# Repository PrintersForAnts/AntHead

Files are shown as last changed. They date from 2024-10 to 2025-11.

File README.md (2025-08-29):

# AntHead
Toolhead for Micron and other PFA printers (Can also work on bigger 2020 based printers with the carriages linked below)

ANTHEAD GHREADME

# [Printed Part Configurator ](https://anthead.wizards-enclave.net/)

# [Color Configurator](https://hartk1213.github.io/ChromaColony/)

## BOM 
* 2x 4010 blower fans 
* 1x 2510 axial fan 
* various m3 hardware 
* BMG extruder kit , or G2 extruder kit (HGX variant is planned)
* Dragon Compatible hotend, Revo Voron, Rapido, TZV6 with or without v6 nozzle
* NOTE: if using a TZV6 hotend with the stock nozzle (small bambu style nozzle) you need to use the dragon hotend mount

What Carriage Do I Print?

Printer  | Rail 
 ----|----|
Micron/SF/Pandora | Stock [MGN9H](https://github.com/PrintersForAnts/Micron/blob/main/STLs/Gantry/Toolhead/MiniSB/MiniSB_x_carriage_MGN9H_x1.stl) | 
Micron/SF/Pandora | Stock [MGN9C](https://github.com/PrintersForAnts/Micron/blob/main/STLs/Gantry/Toolhead/MiniSB/miniSB_x_carriage_x1.stl) |
Micron/SF/Pandora | Chirpy  [MGN9H](https://github.com/chirpy2605/voron/blob/main/general/Alternative_Voron_Mounts/Modified_Mounts/Micron_Pandora/STLs/X_Carriage_MGN9H_Micron_Long.stl)
Micron/SF/Pandora | Chirpy [MGN9C](https://github.com/chirpy2605/voron/blob/main/general/Alternative_Voron_Mounts/Modified_Mounts/Micron_Pandora/STLs/X_Carriage_MGN9C_Micron_Long.stl)
V0 | Stock works but i recommend Chirpys that can be found [here](https://github.com/chirpy2605/voron/blob/main/general/Alternative_Voron_Mounts/Modified_Mounts/v0.2) 
V2/Trident | [MGN12H/MGN9H](https://github.com/PrintersForAnts/AntHead/tree/main/STLs/2020_Carriage)

## Future Plans ##
* HGX Based extruder
* Revisit BMG based extruder
* Bowden option
* larger variety of hotend mounts

## Change log ##

### 8-2-2025
* fixed offset between ducts and probe mounts that was introduced with the previous fix 

### 7-28-2025
* fixed offset between hotend mount and rear of ducts causing toolhead to tilt
* added flanged m2 heatsets in the filament path between the main body and hotend mount for use with the leafcutter 

### 6-15-2025
* Uploaded first version of assembly Manual 

### 6-10-2025
* Updated WWG2, fixed minor printablity issues
* fixed alignment on the filament sensors screw holes

### 5-27-2025
* Added Stealthfork Logo main body and LED files
* Added X endstop cable channel to the 2020 Carriage

### 4-15-2025
* Fixed fitment issue with ReVolcano mount 

### 4-11-2025
* Fixed G2 tension arm spring counterbore,
* Added Ziptie mounts for easier wire management behind ducts
* Updated Tension arm built in support

### 2-17-2025
* Updated all hotend mounts to now work with LeafCutter 
* Added new Left Ducts for LeafCutter
* Added cutting arm and blade holder
* Hotend mounts and main bodies were also merged with leafcutter, now stock and cutter bodies and hotend mounts are the same files
* Added missing tzv6 mounts and re uploaded latest hotend line up cad file

### 2-6-2025
* updated all hotend mounts to fix the mounting screw length to m3x25
* added support for Dragon Ace hotend
* added support for ReVolcano (Revo voron heatsink with hemera heatbreak and volcano heater)
* fixed rapido mount to use correct mounting m2.5 screws 

### 01-05-2025
* updated rapido mount to sit lower for HF and UHF ducts
* fixed fan intake hole size on right ducts
* added updated hotend mounts with HF and UHF nozzle location
* Added CAD and STLs for new 2020 printer carriage for MGN12h and MGN9h

### 10-30-2024
* Updated CAD to v29
* missed exporting latest right fan ducts from previous commit, they worked but had an extra chamfer that needed to be removed  

### 10-29-2024 #2
* modified main housing to now support Sherpa bolt pattern as well as Orbiter 2 bolt pattern
* ducts were updated to fit the latest change
* a Base Grill cad file was uploaded so custom grills can be made 

### 10-29-2024 #1
* Fixed an issue that was introduced with the latest LED changes from 10-28
* updated main housings, and Cad file

### 10-28-2024
* Updated assembly to v20
* Updated the LED to use the same style as Stealthburner that inserts from the bottom 
* Fixed orientation of various files 

### 10-17-2024
* Added latest CAD assembly
* removed recesses in main housing as they arent needed anymore since hotend mount screws are recessed into the printed part
* added a Voron logo variant of the main body 
* added LED logo parts for both Micron and Voron logo 
* added a dual filament sensor WWG2 variant extruder as the default extruder option in CAD 
* organized files a bit more

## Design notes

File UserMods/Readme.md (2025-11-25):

# Anthead Mods

Various mods for AntHead project
Remember to update this README when uploading new mod!

Update the following table with the information about your mod:
- Your name
- A link to your sub-folder
- A short description of your mod
- On which version of the Anthead is this mod made

| Creator | Mod title | Description | Based on Version
| --- | --- | --- | --- |
| Averen | [LED Solder Fixture](/UserMods/LED_Solder_Fixture) | Fixture for soldering up Nozzle LEDs and Body LED | Version V63 |
| Hoeby | [ZeroClick on left ducting](/UserMods/ZeroClick_left_ducting) | Using ZeroClick on the side, to keep space in the back | Version V43 |
|| [Mainbody HexZero logo](/UserMods/Main_Body_HexZero_logo) | The AntHead mainbody with the HexZero logo, incl. led | Version V43 |
| MakerMylo | [Screwless Hotend Fan Mount](/UserMods/Screwless_Hotend_Fan_Mount) | A mount for the hotend fan that uses pegs to attach to the hotend. | Version V50 |
| theFPVgeek | [Papilio Lite Extruder AntHead Mod](/UserMods/Papilio_Lite_Extruder_AntHead_Mod) | Papilio Lite Extruder modified for AntHead | Version V43 |
| Cyph3r42 | [Wristwatch-BMG dual sensor Extruder](/UserMods/Wristwatch-BMG) | A4T WW-BMG Extruder modified for AntHead | Version V72 |
| burkfers | [Bearing cutting surface](/UserMods/Bearing_cutting_surface) | Uses a small MR63 or 683 bearing as a shearing surface for leafcutter | Version V72 |
| hartk | [Crossbow](/UserMods/hartk/crossbow) | mount to use the crossbow filament cutter | latest |
|| [Trident Umbilical](/UserMods/hartk/Trident_Umbilcal) | umbilical mount for trident| latest |

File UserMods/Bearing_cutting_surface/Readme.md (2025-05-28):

# Bearing cutting surface
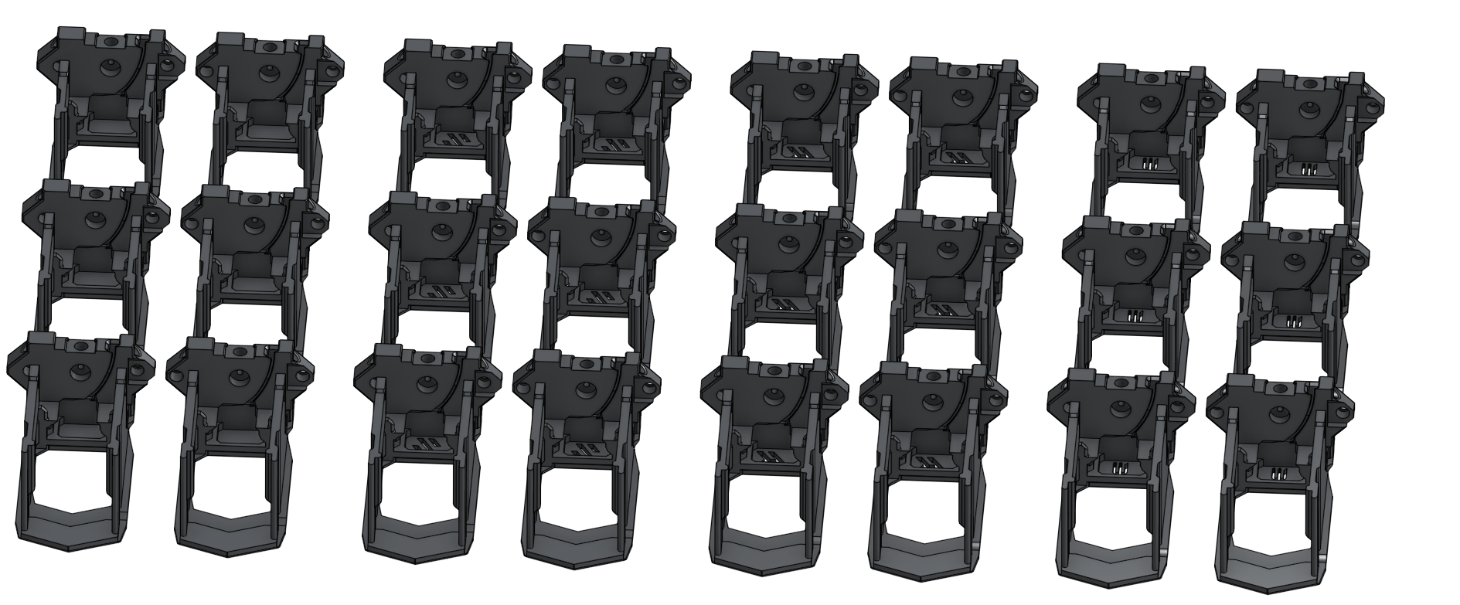
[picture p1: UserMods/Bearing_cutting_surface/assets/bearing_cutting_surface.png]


This mod replaces the main body to provide a pocket for a small bearing which will act as the shear surface for leafcutter.

To avoid tiny pieces of PTFE, the filament path is a printed 2mm diameter.

Variants for MR63ZZ bearings (6mm outer diameter, 2.5mm depth) and 683 bearings (7mm outer diameter, 3mm depth) are provided.

## Instructions
A fitment test is provided. Please print it oriented as presented to ensure it's printed in the same orientation as the full part.

Pick your desired logo, extruder mounting pattern and length for your bearing type. Print as provided, same as the original.
Ream out the filament path with a 2mm drill bit, and press the bearing into place. Glue should not be necessary.

## Caveat
The 683 bearing versions are untested, and the bearing pocket might collide with the "neck screw" heat set insert.

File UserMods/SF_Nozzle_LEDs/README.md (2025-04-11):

# Nozzle LEDs for Standard Flow Anthead

Print 1 each of the following and assemble as per the photos:
- [a]_Nozzle_LED_Carrier.stl
- [a]_Nozzle_LED_Restraint.stl

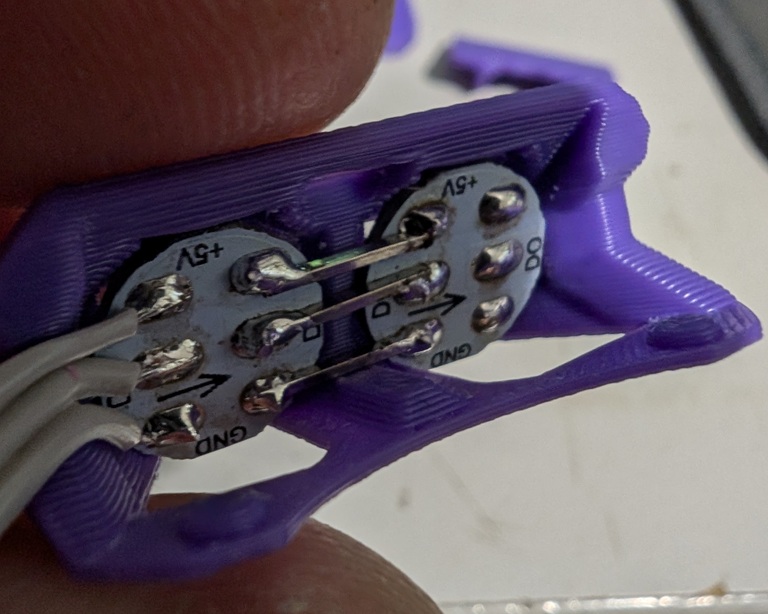
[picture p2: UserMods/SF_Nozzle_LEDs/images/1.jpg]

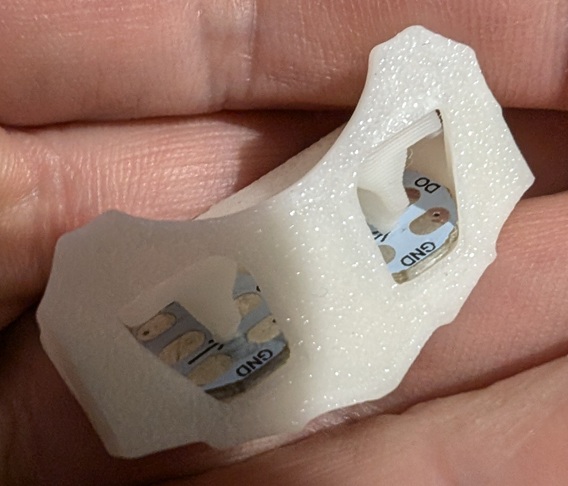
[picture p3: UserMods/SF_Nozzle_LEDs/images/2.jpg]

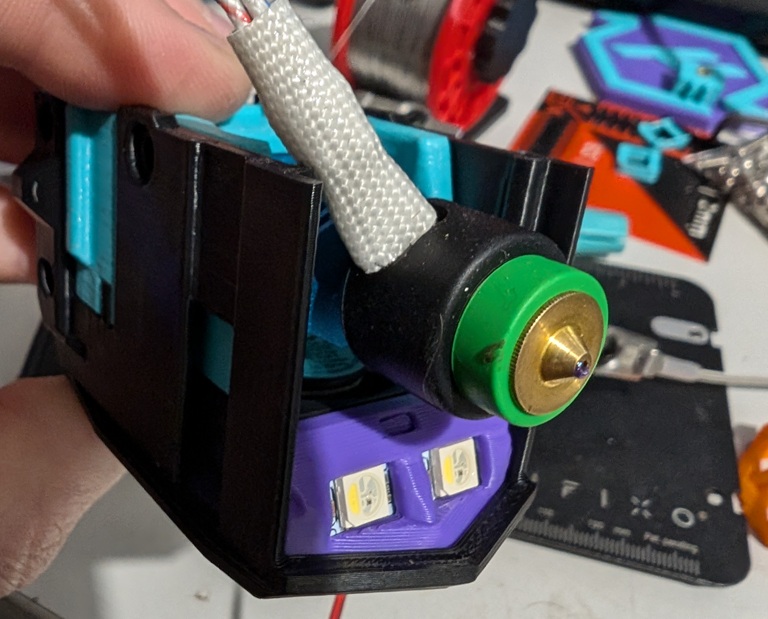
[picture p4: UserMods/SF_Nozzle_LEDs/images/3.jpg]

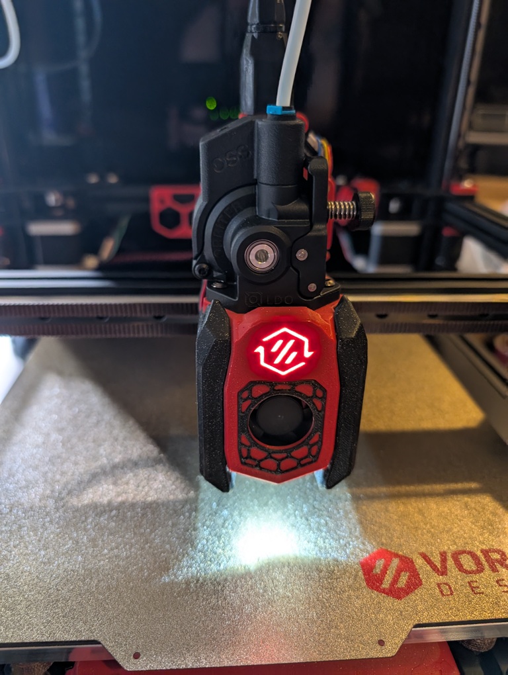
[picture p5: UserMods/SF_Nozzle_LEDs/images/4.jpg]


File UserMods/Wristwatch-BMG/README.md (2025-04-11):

[][cc-by-nc-sa]

# CURRENTLY IN BETA - USE AT YOUR OWN RISK

# AntHead WW-BMG: Wristwatch using Bondtech RIGDA with dual filament sensors for the AntHead toolhead
Originally designed by [ByThorsThunder](https://github.com/bythorsthunder) and adapted for the [A4T toolhead](https://github.com/Armchair-Heavy-Industries/A4T) by [DW-Tas](https://github.com/DW-Tas). Adapted from that adaptation for the [AntHead](https://github.com/PrintersForAnts/AntHead) toolhead (v72).

### Discord links
For discussions around AntHead checkout the PrintersForAnts section at the DoomCube discord. </br>
(https://discord.gg/armchairengineeringsux)</br>
For discussions around the A4T toolhead checkout Armchair Heavy at their discord. </br>
Join me on Discord (https://discord.gg/armchairengineeringsux)
</br>

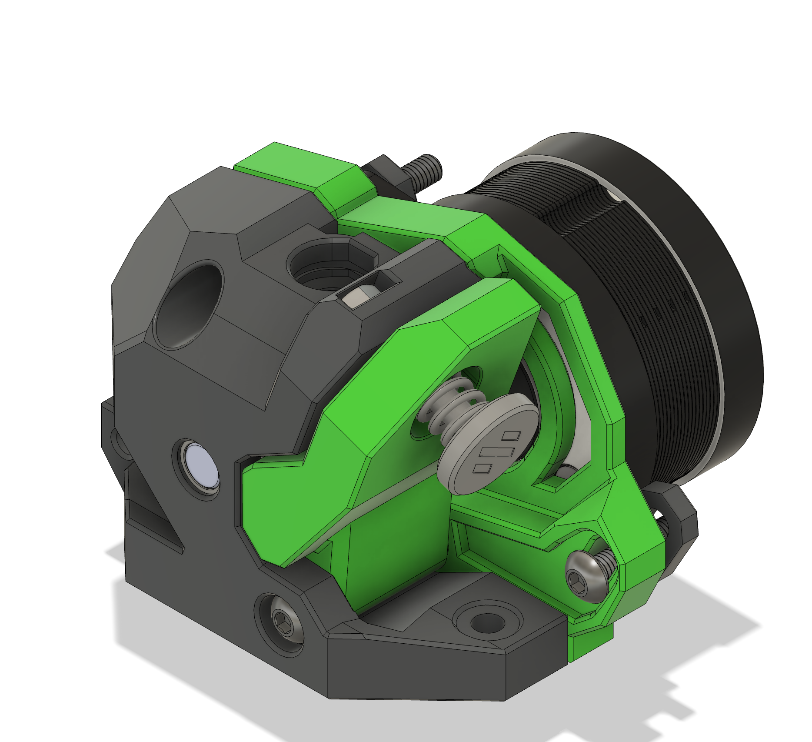
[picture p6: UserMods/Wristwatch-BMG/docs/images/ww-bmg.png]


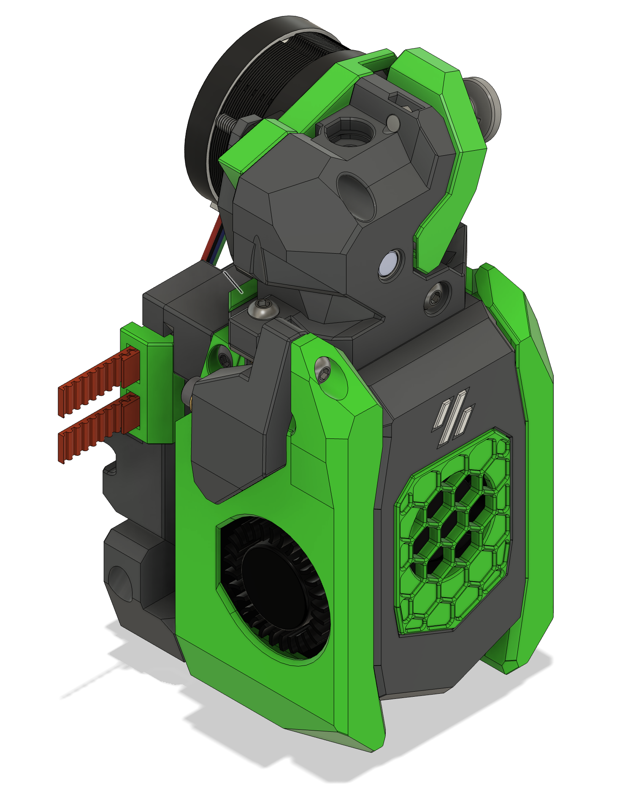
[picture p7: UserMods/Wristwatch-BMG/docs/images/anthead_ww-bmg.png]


<br/> 
I had BMG gears lying around and wanted to use that for an AntHead build to use with BoxTurtle. The A4T adaptation already had the dual sensors and just needed some tweaking to make it work with AntHead and LeafCutter. <br/><br/>

## Bill of Materials (BOM)
***`*Not including carriage hardware`***
| Qty | Item | Notes |
| --- | --- | --- |
| 2 | M3 Nut | Using normal nuts because you probably have them. Tolerances should be tight enough to prevent spin. |
| 1 | M3 x 20 BHCS | Top Motor screw.  At least M3x18 BHCS |
| 3 | M3 x 14 BHCS | Bottom Motor mount.  You'll need M3x14 for mounting to the AntHead and for the LeafCutter lever arm | 
| 1 | M3 x 12 BHCS | Second mounting screw for the AntHead |
| 1 | M3 x 30 BHCS				| Mount Tension arm to body |
| 1 | ECAS | |
| 1 | RIDGA / BMG hardware set | If standard BMG configure for RIDGA |
| 2 | 20mm long 3mm internally threaded stand off  | To attach toolhead board to the back of the extruder motor |

## Printing parts
### Print settings
Parts are meant to be printed in 0.2mm layer heights, 0.25mm first layer should be OK. Anything else will likely cause the built-in supports to fail or fuse to the printed part.<br/>
Print testing is still TBD<br/>

Voron settings are a good starting point for 0.4mm wall widths (four walls, 5 top/bottom layers and 40% infill).<br/>

### Credits
* Huge thanks to DW-Tas for the bulk of the modifications to the Wristwatch for dual sensors
* Also big thanks to ByThorsThunder for the original design

This work is licensed under a
[Creative Commons Attribution-NonCommercial-ShareAlike 4.0 International License][cc-by-nc-sa].

[][cc-by-nc-sa]

[cc-by-nc-sa]: http://creativecommons.org/licenses/by-nc-sa/4.0/
[cc-by-nc-sa-image]: https://licensebuttons.net/l/by-nc-sa/4.0/88x31.png
[cc-by-nc-sa-shield]: https://img.shields.io/badge/License-CC%20BY--NC--SA%204.0-lightgrey.svg

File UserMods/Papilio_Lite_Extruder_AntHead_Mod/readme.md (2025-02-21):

# AntHead Papilio Lite Mod

In Progress:  Leafcutter (Filament Cutter) + Integrated Runout Sensor









## About
AntHead modified to integrate Papilio Lite<br>
Wanted to lower the height of a standard AntHead with standard Papilio Lite extruder.<br>
Thanks [hartk](https://github.com/hartk1213) the creator of the AntHead [Anthead](https://github.com/PrintersForAnts/AntHead) and [Kevinakasam](https://github.com/kevinakasam) the creator of the Papilio Lite [Papilio Lite](https://github.com/theFPVgeek/Papilio-Belt-Extruder/) for having solid base to use to make this work. <be>




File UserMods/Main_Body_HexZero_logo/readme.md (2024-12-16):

# MainBody with HexZero logo included led option
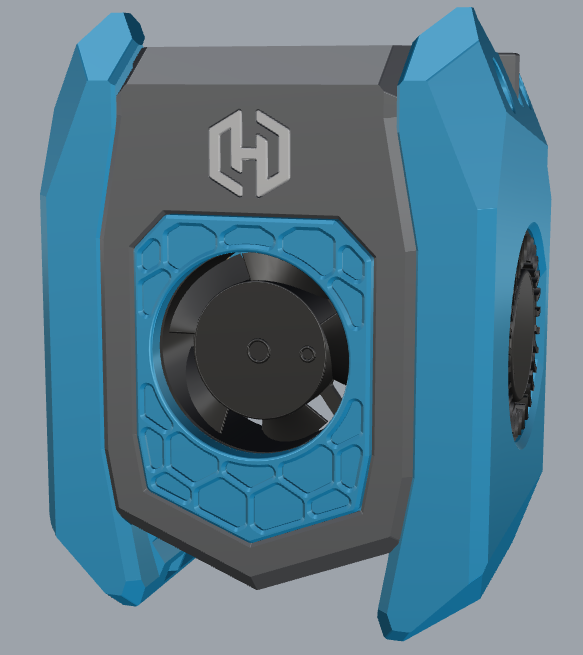
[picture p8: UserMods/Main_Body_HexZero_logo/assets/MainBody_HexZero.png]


This mod is made for the HexZero. <br>
[Github link HexZero](https://github.com/Alexander-T-Moss/Hex-Zero) 

## Which 3d parts are shared
Only the modded parts can be find in this mod. <br>
This includes the parts for the led. <br>
Non modded parts, that are the default AntHead parts and can be find in de main repository of the AntHead. <br>
The parts are made on AntHead version43

## Be carefull
Be carefull when you assemble the led.
Because of the design of the HexZero logo and the space that is availble, the parts are thin.
Take this in care, when you assemble the mainbody.

## Hardware needed for this mode
### For the AntHead
Nothing extra is needed for the AntHead, when looking at the hardware. <br>

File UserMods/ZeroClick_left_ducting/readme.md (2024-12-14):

# ZeroClick on left ducting
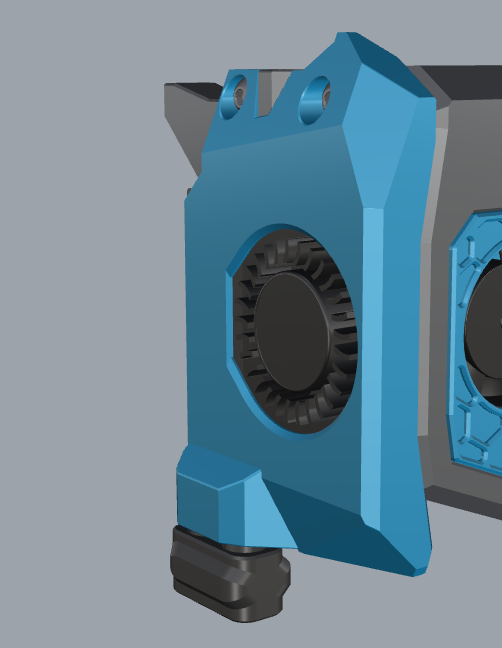
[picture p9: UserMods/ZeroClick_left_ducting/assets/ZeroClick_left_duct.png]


## Idea about this mod
This mod is started for the HexZero. <br>
The HexZero has the dual extrusions in the back, like the Voron V0.2. <br>
On the HexZero the change is made, that the gantry can move over these dual extrusions. <br>
There is that little space, that there can't be parts on the back of the toolhead, because these would collide with these Z-extrusions. <br>
This mod moves the probe to the side, to give free space on the back, to prevent this collision. <br>
[Github link HexZero](https://github.com/Alexander-T-Moss/Hex-Zero) 

## Which 3d parts are shared
Only the modded parts can be find in this mod. <br>
Non modded parts, that are the default AntHead parts and can be find in de main repository of the AntHead. <br>
Only the standard fan is modded. Other fan ductings are not changed, but could be done by de delivered CAD.

## Hardware needed for this mode
### For the AntHead
Nothing extra is needed for the AntHead, when looking at the hardware. <br>
### For the ZeroClick
The default parts for the ZeroClick are needed. <br>
Extra parts could be the parts for the dock, depends on the user choice, what to use. <br>
For the ZeroClick follow there github. <br>
[Github link ZeroClick](https://github.com/zruncho3d/ZeroClick) 

## How to wire the ducting
Before following the ZeroClick manual, the explanation how the wiring has to be done
### Step 1
Start by placing wire in the wire-guide of the front magnet-hole and let it stick out of the back. <br> 
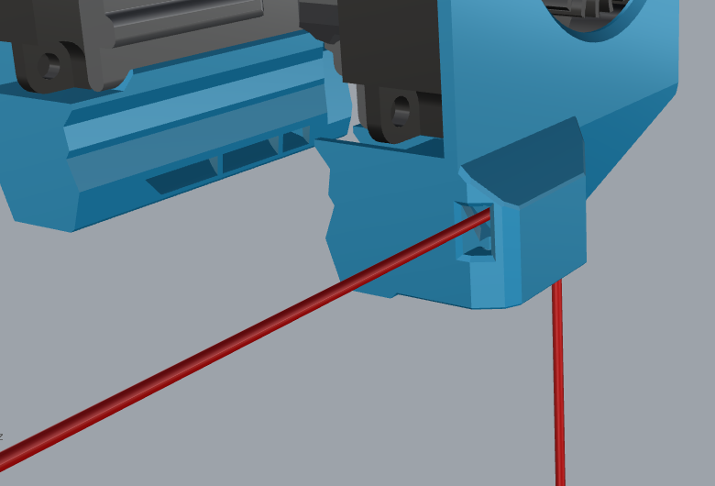
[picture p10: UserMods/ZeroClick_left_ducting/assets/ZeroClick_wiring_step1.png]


### Step 2
Loop back the wire and place it back in the hole it comes out, but now in the wire-guide that goes underneat the fan. <br> 
Carefully pull on the wire end and help them, that the loop disappears inside the ducting, and nothing is sticking out the back. <br>
Not easy to draw in Rhino, to make a wire loop, but you will get it what i mean :blush: <br>
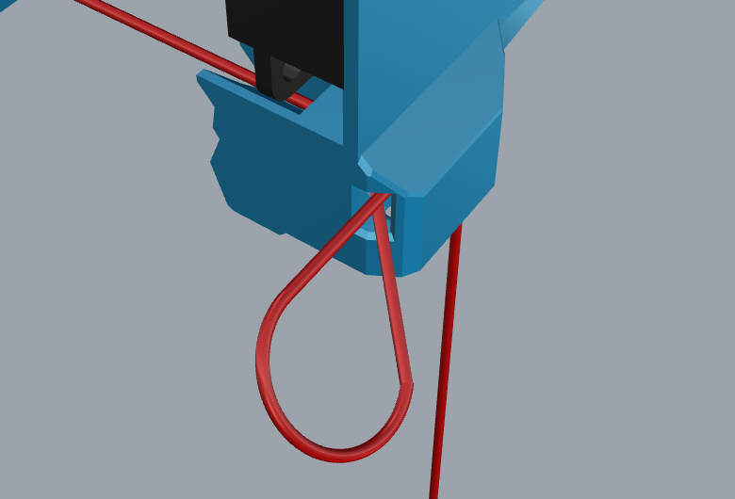
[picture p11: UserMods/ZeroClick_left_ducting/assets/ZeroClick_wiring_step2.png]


### Step 3
Place the wire-guide of the back magnet-hole. <br> 
This wire-guide hole is almost in line with the wire-guide underneat the fan, that you can route it in a single job. <br>
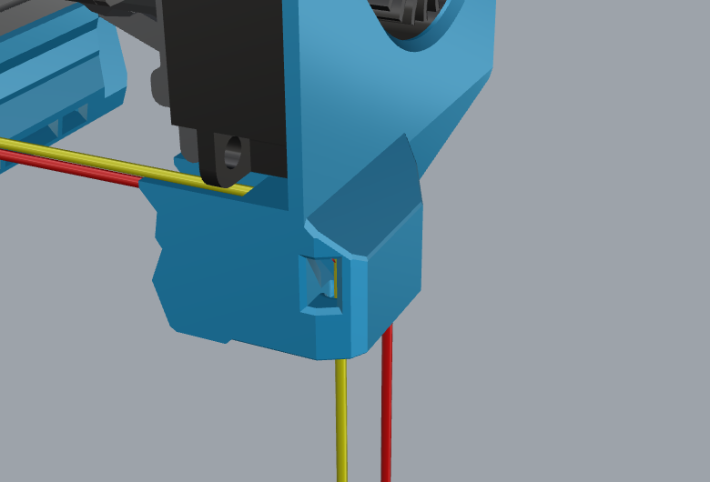
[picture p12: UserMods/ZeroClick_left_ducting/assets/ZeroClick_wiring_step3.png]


### Step 4
Now that the ZeroClick wires are near the fan, follow the wire route of the fan.
How to finish the wiring for the ZeroClick magnets, see the ZeroClick manual on there github

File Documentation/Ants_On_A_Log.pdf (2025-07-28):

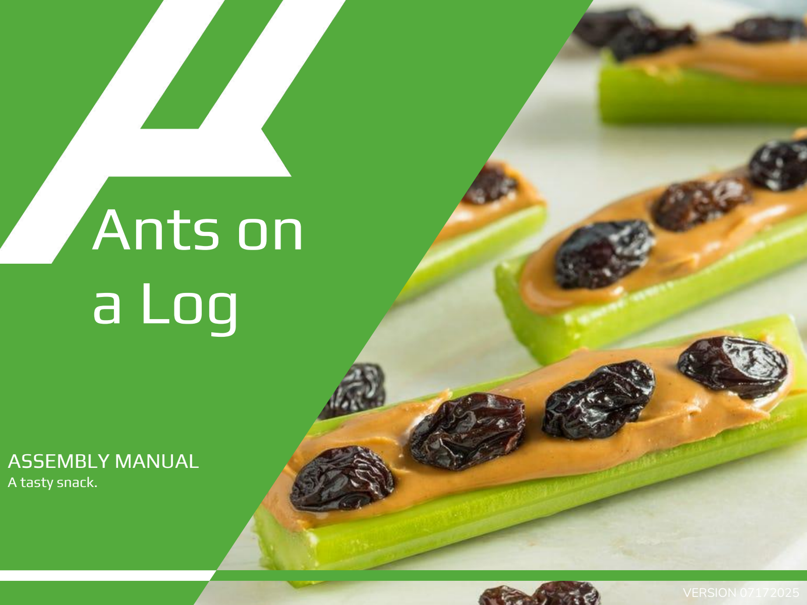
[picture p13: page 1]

# ASSEMBLY MANUAL

A tasty snack.

# Ants on a Log

### VERSION 07172025

TABLE OF CONTENTS

TABLE OF CONTENTS

Ants on a Log

Description | Page | Description | Page
1 | Introduction | 3
2 | Prep Work | 4
3 | Assembly | 5

2

INTRODUCTION

Ants on a Log | 3

### Ants on a Log

### Ants on a log is a wonderful snack that is super easy to make. Ready in no time you can have a tasty snack that will nourish your mind and body to help you finish building your toolhead, printer, or what ever other project you are tackling! You only need the three

following ingredients to make this wonderful snack.

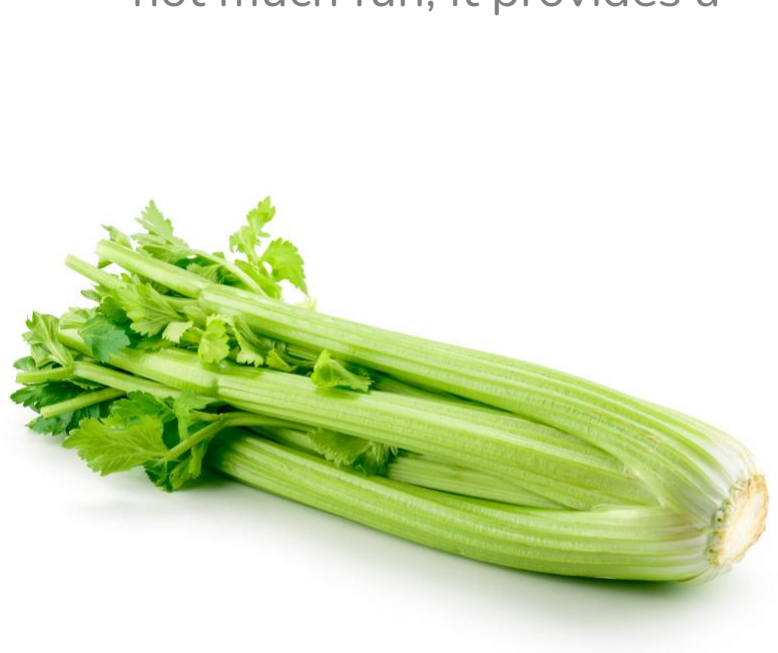
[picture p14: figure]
base for this yummy snack.

Celery
While on its own celery is not much fun, it provides a

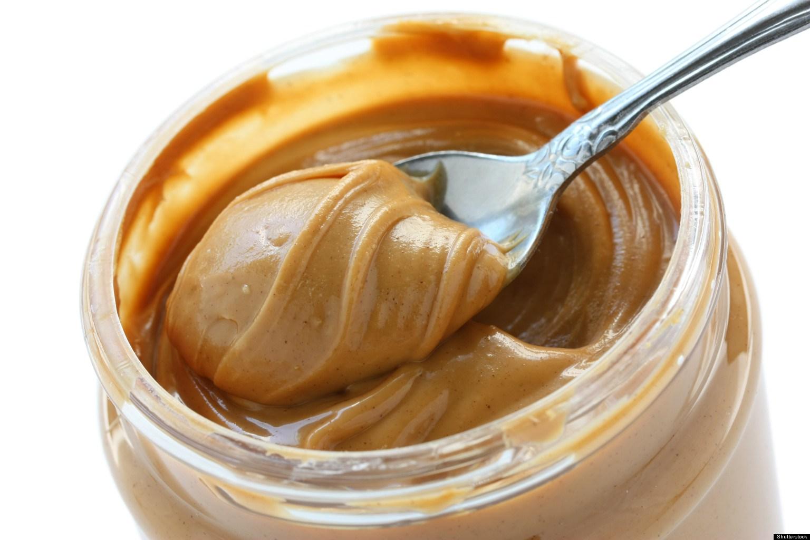
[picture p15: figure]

Peanut Butter
This will be the core and
glue that holds this snack together.

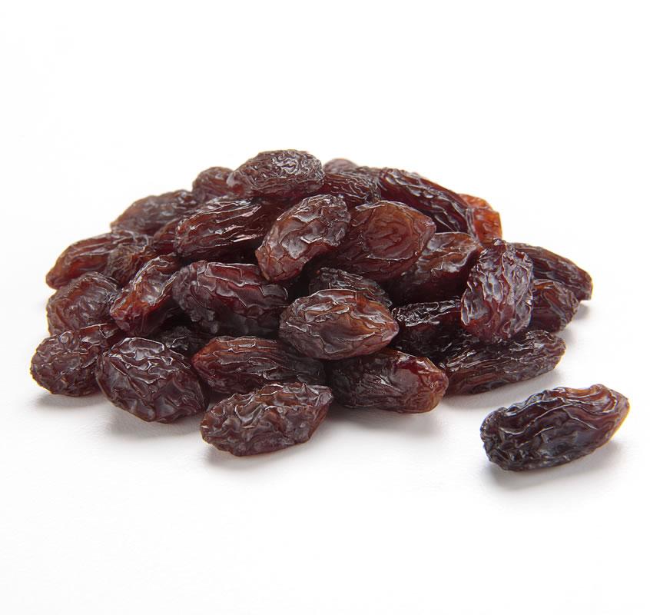
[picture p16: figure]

Rasins
The tasty toppers to our
wonderful snack.

INTRODUCTION

### Prep Work

You will need to do a little prep work before beginning to make your snack.

### Next you will need to wash your celery. (unless you bought it pre cleaned and cut)

The last bit of prep work will be chopping your celery into sections that are about 3 inches

### long. Be careful to only cut the celery and not yourself!

Area Prep
The first thing you will
want to do is ensure you
have a clean work area.
Wipe the area down with
a food area safe cleaning
solution.

Clean Your Celery
Next you will need to
wash your celery.
(unless you bought it pre
cleaned and cut)

Chop Your Celery
The last bit of prep work
will be chopping your
celery into sections that
are about 3 inches long.

Be careful to only cut the celery and not yourself!

You will also want to have a plate or some other means of containment for your snacks once they are prepared.

### Assembly

INTRODUCTION

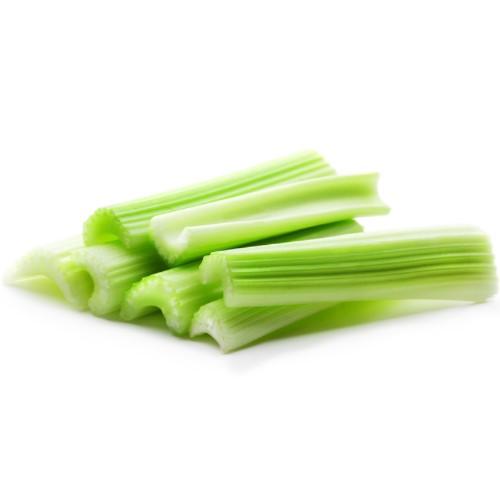
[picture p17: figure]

Get Your Celery
Place your celery stick with the channel facing up in your hand.

Make sure you have a solid grip on it.

### Assembly

INTRODUCTION

Add Peanut Butter
Using a spoon spread a good amount of peanut butter in the channel of your celery. Make sure you get a good thick coating and don’t skimp here!

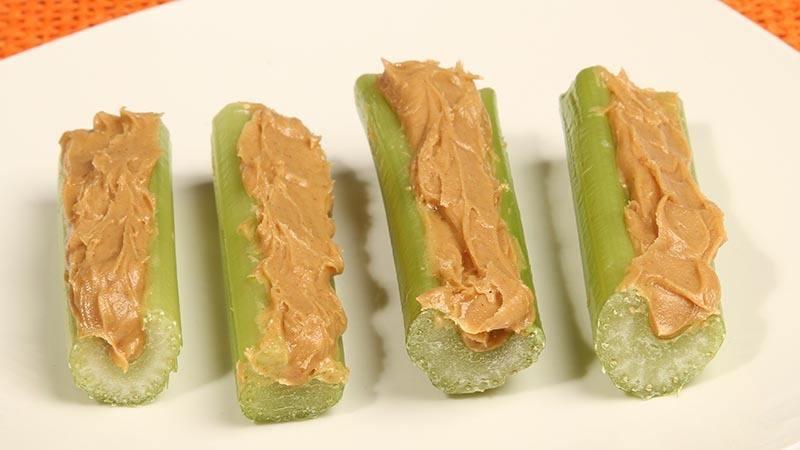
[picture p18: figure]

### Assembly

INTRODUCTION

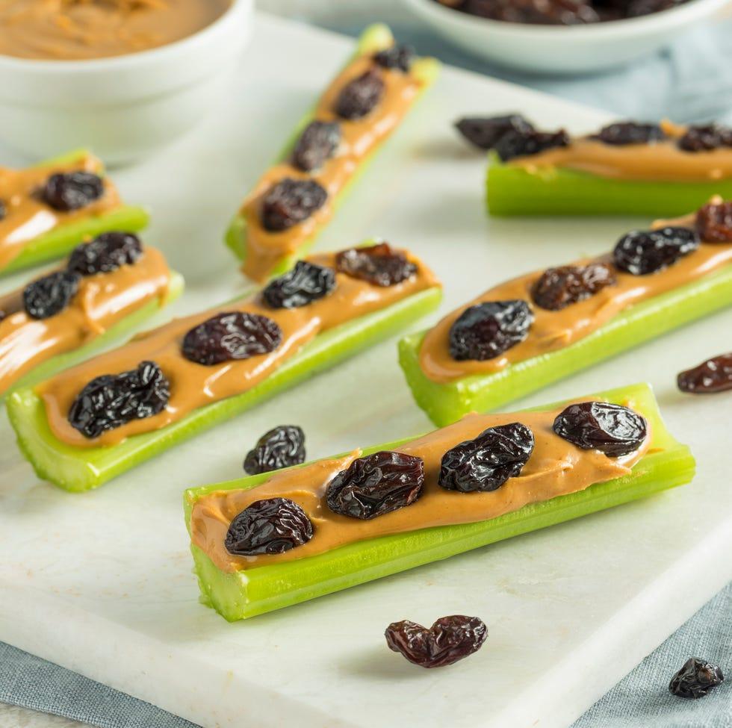
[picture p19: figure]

Place Your Ants
Now comes the fun part! You get to put your ants on the log!

Take your raisins and line them up down the peanut butter in a little row.

### Ants of the World

INTRODUCTION

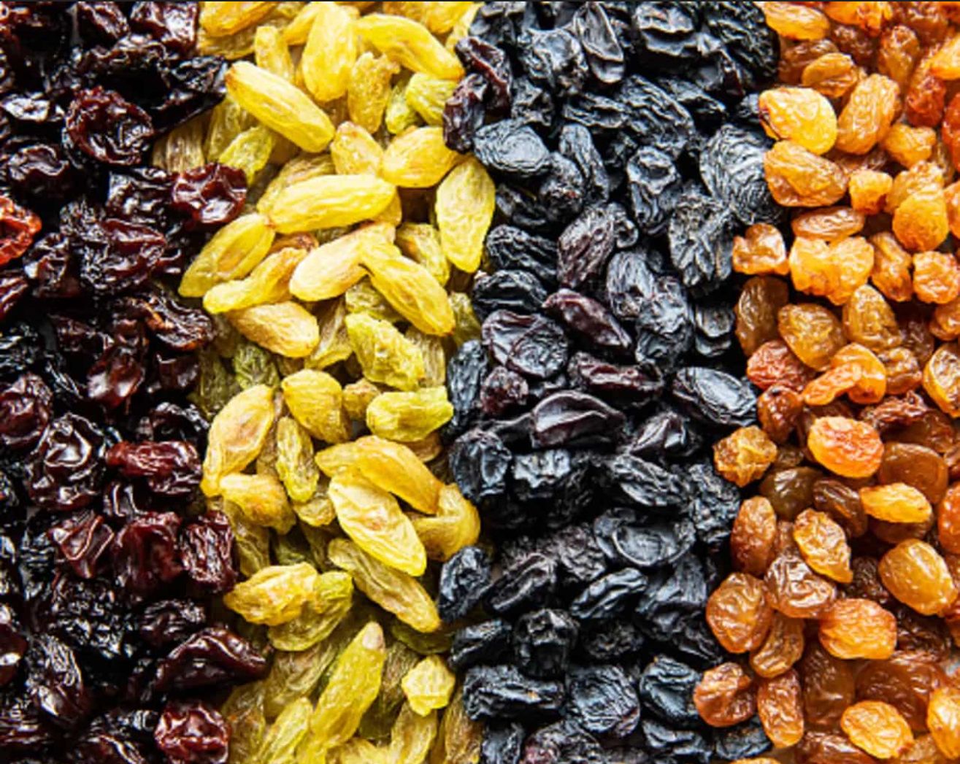
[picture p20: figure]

Many Kinds of Ants in the World
There are many kinds of ants in the world in many different colors and sizes. Have fun, mix things up, and try them all!

### Enjoy!

INTRODUCTION

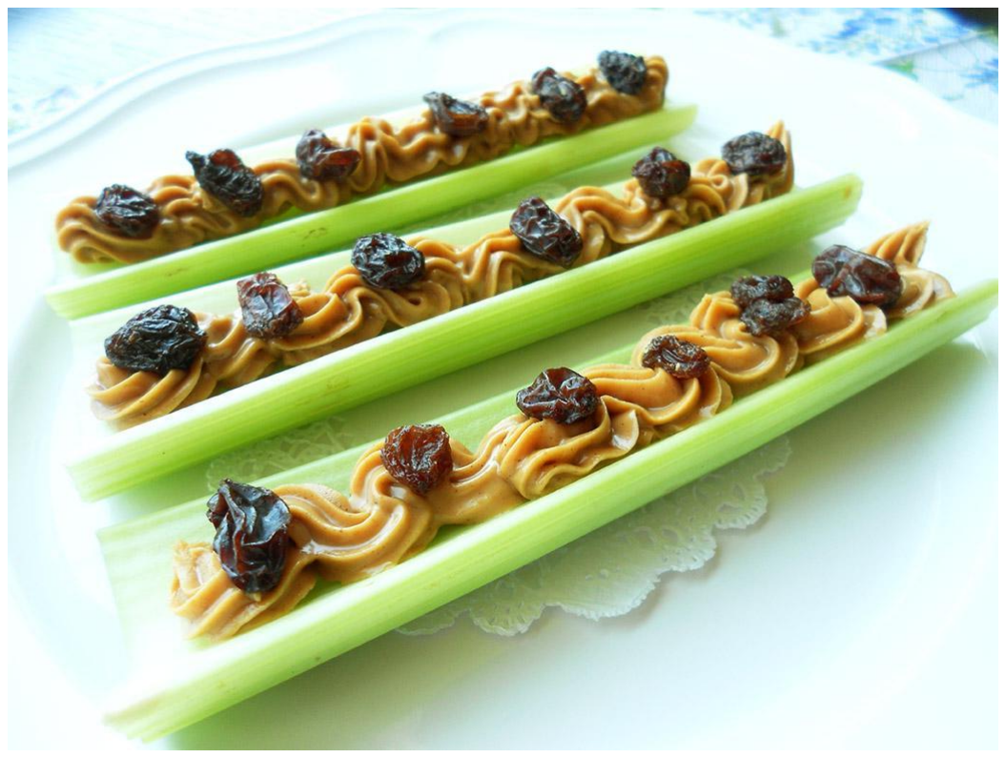
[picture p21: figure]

Enjoy!
Now that you have made your super posh and delicious snack enjoy it! Because soon it will be time to get back to working on printers!

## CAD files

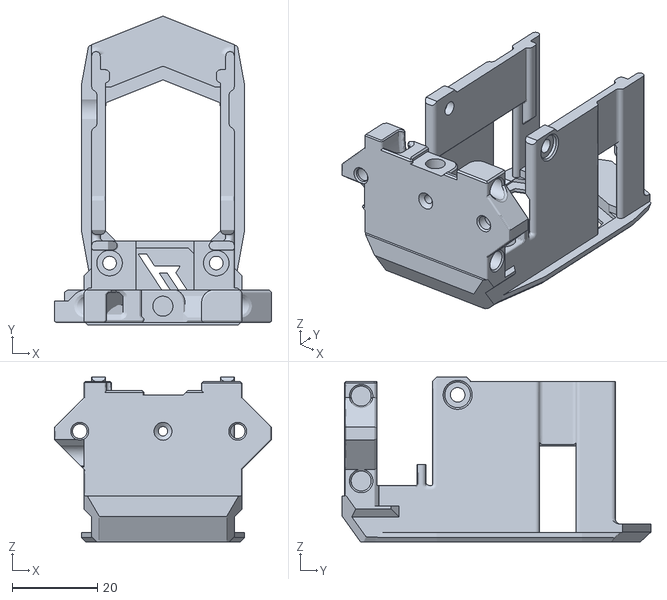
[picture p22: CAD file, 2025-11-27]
STLs/Main_Bodies/O2/Micron/ant_head_main_body_micron_o2_hf_x1.stl
50.8 x 72.3 x 38.6

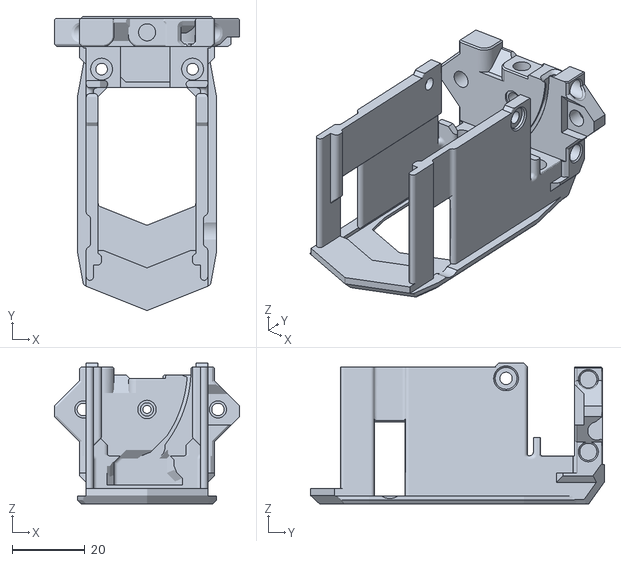
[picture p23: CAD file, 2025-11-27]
STLs/Main_Bodies/O2/No_Logo/ant_head_main_body_no_logo_o2_uhf_x1.stl
50.8 x 80.8 x 38.6

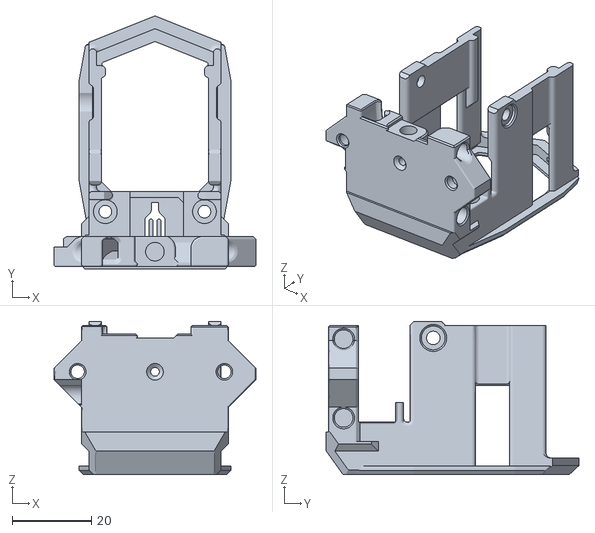
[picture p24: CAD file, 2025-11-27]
STLs/Main_Bodies/O2/SaladFork/ant_head_main_body_saladfork_o2_sf_x1.stl
50.8 x 63.8 x 38.6

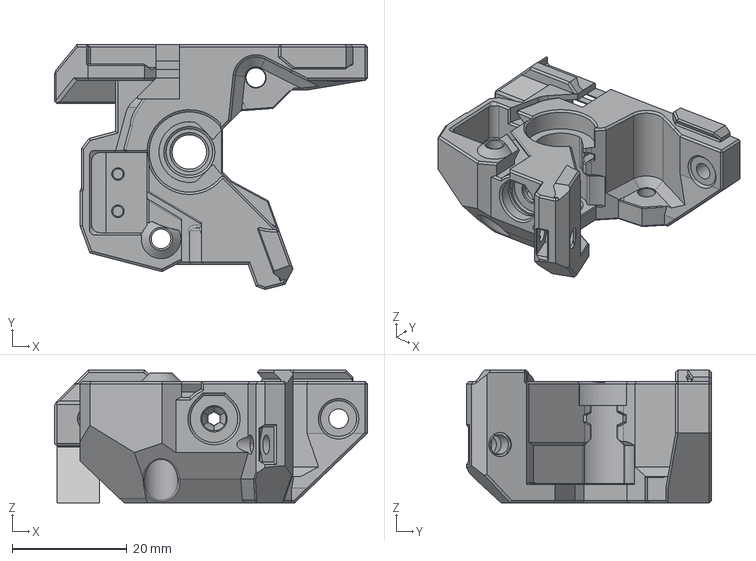
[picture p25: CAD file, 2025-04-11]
UserMods/Wristwatch-BMG/CAD/AntHead WW-BMG - Main Body.step
54.6 x 42.8 x 23.2 mm

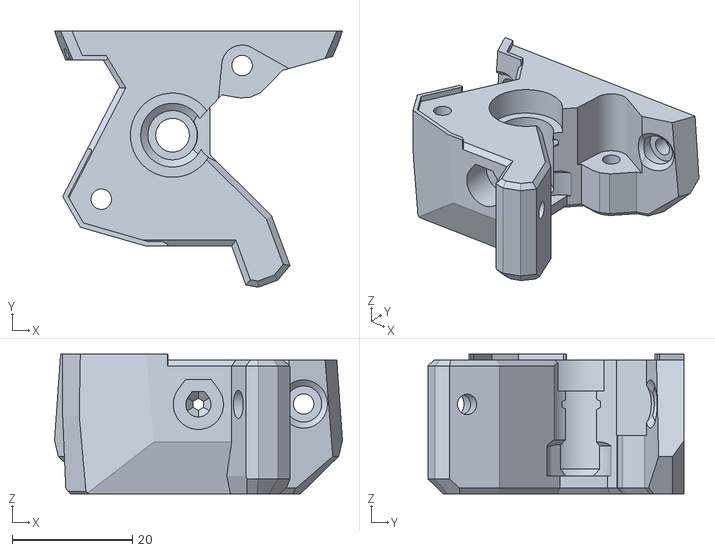
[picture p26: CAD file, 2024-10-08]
STLs/Extruders/BMG/extruder_main_body_x1.stl
47.9 x 42.7 x 23.3

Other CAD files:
STLs/Main_Bodies/O2/StealthFork/ant_head_main_body_stealth_fork_o2_uhf_x1.stl
STLs/Main_Bodies/O2/Voron/ant_head_main_body_voron_o2_hf_x1.stl
STLs/Main_Bodies/Sherpa/Micron/ant_head_main_body_micron_sherpa_hf_x1.stl
STLs/Main_Bodies/Sherpa/No_Logo/ant_head_main_body_no_logo_sherpa_uhf_x1.stl
STLs/Main_Bodies/Sherpa/SaladFork/ant_head_main_body_saladfork_sherpa_hf_x1.stl
STLs/Main_Bodies/Sherpa/StealthFork/ant_head_main_body_stealth_fork_sherpa_hf_x1.stl
STLs/Main_Bodies/Sherpa/Voron/ant_head_main_body_voron_sherpa_hf_x1.stl
UserMods/Bearing_cutting_surface/CAD/683/Main_Body_Voron_Sherpa v4_683.step
UserMods/Bearing_cutting_surface/CAD/MR63ZZ/Main_Body_Voron_O2_UHF v4_MR63ZZ.step
STLs/Main_Bodies/O2/Micron/ant_head_main_body_micron_o2_sf_x1.stl
STLs/Main_Bodies/O2/No_Logo/ant_head_main_body_no_logo_o2_sf_x1.stl
STLs/Main_Bodies/O2/SaladFork/ant_head_main_body_saladfork_o2_hf_x1.stl
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

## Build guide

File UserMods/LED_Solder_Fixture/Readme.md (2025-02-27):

# AntHead LED Solder Fixture
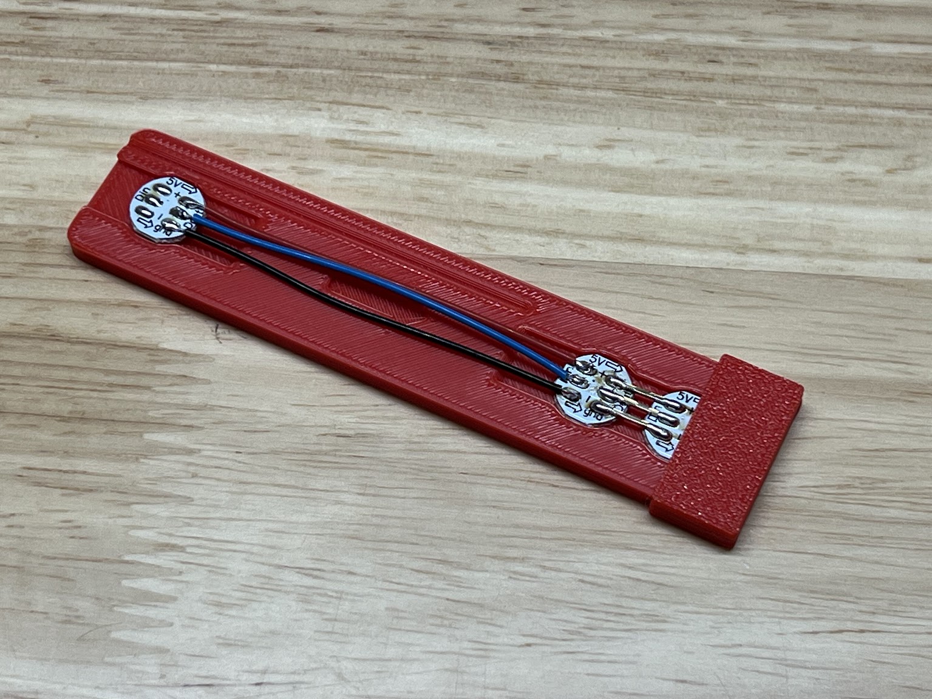
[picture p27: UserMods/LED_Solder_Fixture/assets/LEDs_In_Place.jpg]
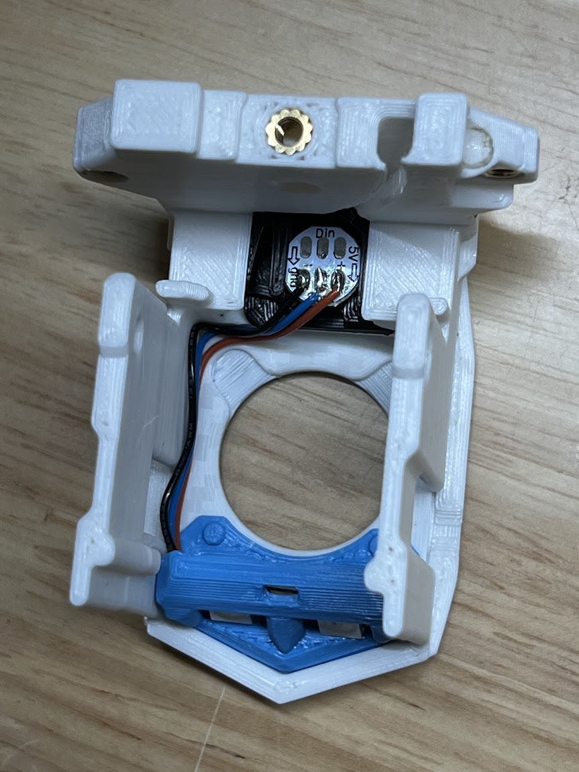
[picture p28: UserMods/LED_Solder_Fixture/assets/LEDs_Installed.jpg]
<p align="center"><br>

## What is this?

This is used to hold the LEDs for soldering when using the Nozzle LEDs and the Body LED in the AntHead.  It also provides a wire length measurement in the groove.  

## How to use

- Use the groove to cut the wires to length
- Insert the LEDs 
- Solder the 2 nozzle LEDs first.  I recommend using some rigid pins or solid wire. Small tweezers help.

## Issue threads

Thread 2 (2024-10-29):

grill no longer fits after new LED insert update

hartk1213, 2024-10-29:
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

Closed 2024-10-29.

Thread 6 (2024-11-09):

HB92 Grill does not fit fan correctly.

dajones89, 2024-11-09:
Left hand duct does not fit the HB92 fan correctly. Due to the position of the hole, the fan blades are partially covered, jammed by the duct.
[left_duct_HB92_x1.stl](https://github.com/PrintersForAnts/AntHead/blob/main/STLs/Ducts/%5Ba%5D_left_duct_HB92_x1.stl)
I had initially fixed this by moving the hole 1.5mm to the rear, sadly no longer have the CAD file but have the 3MF that I could share.

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

dajones89, 2024-11-09:
Just to add, the right hand side does fit correctly

Closed 2024-12-14.

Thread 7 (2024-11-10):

Duct face is unnecessarily thin

PedroC1999, 2024-11-10:
Although what could be partially blamed on my cheap fan or printer calibration, I have found the fan ducts to be a bit weak during assembly and crack if the fan fit isn't perfect. I have also found that my Kingroon fan blades (HB form factor using HB ducts) protrude further than the duct face

"Pulling" the face 0.5mm is enough to fit 4 complete walls, instead of 2 walls + gapfill and means the fan blade now sits closer to flush and is protected during potential sensorless homing. 0.5mm pull means the geometry is unchanged (atleast using the HB ducts) and the styling is therefore unaffected. This added thickness allowed me to assemble the ducts without cracking and with alot more confidence.

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

pm0u, 2025-06-12:
Maybe its your wall generator? I was able to get 4x walls in this area with arachne and 55% min wall width (might not be necessary to go that low). Inner walls ended up around 0.24mm.

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

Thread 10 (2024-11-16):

3010 hotend fan for us Europeans ? :)

ga73, 2024-11-16:
Awesome design but 2510 (at least delta fans) are hard to source in Europe or shipping is way more than the cost of the fan!!

Any thoughts of a design which will accept 3010 hotend fans for us Europeans ? 👍

EllaFoxo, 2024-12-10:
@ga73 I got mine from 3Dkatten in Sweden. Might suggest taking a look there? 😄

https://3dkatten.se/en/products/delta-2510-5v

azak1r, 2025-02-21:
i got them from digikey in europe. in order to save on shipping i ordered multiple things like 2510's aswell as other goodies for the toolhead (running 6)

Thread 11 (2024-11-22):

30mm hotend screws bottom out on all carriages

Foofinator94, 2024-11-22:
The update to 30mm length from 25mm doesn't work right now. The screws bottom out on both printed and CNC carriages before fully clamping the hotend mount.

Reccomend to make the clamped thickness increase by ~0.8mm to accomodate, or revert to the previous design with 25mm screws as that was working fine.

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

hartk1213, 2024-12-16:
where did you see that it uses 30mm? those should still be 25mm

Foofinator94, 2024-12-16:
The previous iterations had more recessed counterbores for the screws, so needed 25mm. The latest didnt have enough thread engaging for 25mm so I thought 30mm was needed.

Closed 2025-02-06.

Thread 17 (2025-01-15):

the bambu x1 hotend needs to shft to the side a little

broncosis, 2025-01-15:
when you put the hotend on its mount into the tool it forces the side of the cowl
out a little bit I will take some pictures and post in a little bit

granted I pulled it out of you hotend line up step file so I don't think its Released yet but I wanted to test I may try and pull it into fusion
and make the slight adjustments just over a millimeter

broncosis, 2025-01-15:
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

broncosis, 2025-01-15:
I made some minor tweaks to hotend mount printing it tonight I will update

@hartk1213  thank you for the work you have put in sofar if this work I will have to figure out git and put in a pull request

broncosis, 2025-01-16:
Yes a 1.1mm adjustment
Was perfect
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

tjeffoo, 2025-04-02:
Where can i get this hotend mount file? Its different from the one in the stl map. With the one in the stl map the x1c hotend does not fit with the stealthchanger backplate. This one is 90 degrees turned.

broncosis, 2025-04-04:
@tjeffoo  are you on the stealth changer Discord message me there I will send you my file to try out

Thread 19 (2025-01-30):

LED Carrier for Rainbow Barf

angaz, 2025-01-30:
It would be pretty cool to have an LED carrier for the [Rainbow Barf](https://github.com/VoronDesign/VoronUsers/tree/main/printer_mods/VinnyCordeiro/RGB_LED_grid_for_SB).

The logo cutout is slightly too small, like 1-2mm, but I think with the diffuser, it will be fine. It just fits into the hole where the LED goes without the carrier, so I guess it should be possible to design.

I exported the PCB as a step file: [RGBW_LED_circular_panel_for_Stealthburner.step](https://github.com/angaz/VoronUsers/blob/daeb15535c91fa9469d36fe5c07573f2e3aefe4d/printer_mods/VinnyCordeiro/RGB_LED_grid_for_SB/KiCad/RGBW_LED_circular_panel_for_St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)

Here are some pictures for reference:

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

angaz, 2025-01-30:
Brainfart moment, I need to print this: https://github.com/tanaes/whopping_Voron_mods/tree/main/LEDs/Rainbow_Barf_Logo_LED

Closed 2025-01-30.

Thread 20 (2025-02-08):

Rapido Hotend Mounts have missing buffer

dazza2924, 2025-02-08:
Looks like that the '[a]_rapido_x1.stl' and '[a]_rapido_m2.5_x1.stl' have a screw hole that is larger than the rest of them, which means that when screwing in the screw for the Rapido Hotend, it will bottom out. Expecting to see all 4 holes be the same (the current 3 holes appear to be correct).

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

Theaninova, 2025-02-22:
Seems like that was fixed in d0741df254f2a084a1baa9b44a569ffbefc1e9f4

Closed 2025-02-27.

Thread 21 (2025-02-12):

Missing leafcutter stl files

ga73, 2025-02-12:
Hi,  seems like some of the stl files are missing for the leaf cutter going from the cad.

Also will you be releasing a rapido mount for the leafcutter as well as revo and dragon versions?

Thanks!

hartk1213, 2025-02-27:
all files have been updated in the main repo , not in the usermods folder

Closed 2025-02-27.

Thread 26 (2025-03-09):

Cartographer CNC adapter 9mm belts doesnt fit right

ga73, 2025-03-09:
Hi,
Tried using the Carto CNC adapter (HF) with a rapido - the adapter, no matter how much it's adjusted is the wrong height to trigger the cartographer.

This is using a cartographer 9mm belt size HF CNC bought directly from them.

Does the adapter only fit 6mm belts ?  if so it maybe good to point this out (and any chance of a 9mm belt version if thats the case ??! :) )

ga73, 2025-04-26:
any chance this could be looked at...would really like to try this toolhead :)

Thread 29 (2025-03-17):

G2 Rear Plate Wire Cut Outs (Stealthchanger)

EddieSha04, 2025-03-17:
When using Anthead/G2 on stealthchangers, the rear plate will pinch the wires on the spacer/backplate.
-Enlarge wire cutout on the right to account for RGB, post sensor wires and thermistor/heater wire.
-Provide cut out on the left for wiring as well.

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

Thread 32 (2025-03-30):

Extruder mounting holes

rbc1225, 2025-03-30:
I printed out both extruders under STLs and then Extruders and neither one of them line up with the mounting holes on the shell. I may be doing something wrong but I then printed out a Sherpa Mini extruder from another source it is spot on to be able be mounted to the shell. As you can see, I printed both bases from the extruder directory and both are spaced the same and don't line up with the shell.  I even tried your adapter plates thinking something would line up there. No luck. Anyway, not exactly sure how this works on Github but that's what I found.

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

bcutty, 2025-03-30:
The two anthead extruders have been altered from the orbiter mounting pattern wwbmg and wwg2, so you’d need to print the orbiter mounting pattern cowl for the holes to line up instead of the sherpa mini one.

rbc1225, 2025-03-31:
> The two anthead extruders have been altered from the orbiter mounting pattern wwbmg and wwg2, so you’d need to print the orbiter mounting pattern cowl for the holes to line up instead of the sherpa mini one.

Ahhh Okay, I will look into that.  Thanks

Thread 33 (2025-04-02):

VORON Mainbody - UHF and HF same size

weismantelf, 2025-04-02:
Hello,

is it correct that the VORON mainbody's UHF and HF have the same size.
I was cross checking with the assembly file and there you have 3 sizes for the main body.

weismantelf, 2025-04-04:
Sorry I was wrong

Closed 2025-04-04.

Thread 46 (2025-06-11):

Add HEF wire routing slots in hotend mounts - @theroguezeta

hartk1213, 2025-06-11:
Along with this, we can also look at removing the slots on the main body that were used to route the fan wires out.

We may want to add additional space in the slot where the wires exit as we are now adding 3 more wires. The Delta fan wires are about 0.95mm in diameter.

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

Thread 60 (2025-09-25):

WWBMG does not have cutouts for wire exits

hartk1213, 2025-09-25:
From Steve Build's stream, there are no wire cutouts on the BMG extruder and does not work with the Vitalii CNC bracket.

<details>
<summary>Context from Discord</summary>

**Submitted by:** `theroguezeta`
[View original Discord message](https://discord.com/channels/825469421346226226/1316975035478577172/1420565895482179636)

</details>

---
**Attached Images:**

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

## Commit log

2024-10-08 initial commit with CAD and STLs more to come soon
    [[a]_dragon_hotend_mount.stl, [a]_fan_grill_hex.stl, [a]_fan_grill_open.stl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]
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2024-10-09 updated STLs and CAD to v7
    added bottom magnets for Stealthchanger compatiblity, added rear heatsets and brace for boop/extra rigidity
    [[a]_dragon_hotend_mount.stl, [a]_dragon_hotend_x1.stl, [a]_fan_grill_hex.stl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]
2024-10-10 hotend mounts and updated cad
    [[a]_bambu_x1.stl, [a]_dragon_hotend_x1.stl, [a]_dragon_x1.stl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]
2024-10-10 Add CAD/Hotend_Base
    [Hotend_Base.step]
2024-10-18 updated Anthead view readme for changelog
    [LGX_Lite_Adapter.step, LGX_Lite_Adapter.stl, [a]_bambu_x1.stl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]
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2024-10-28 updated LED files and fixed orientation of G2 parts
    [[a]_front_body_x1.stl, [b]_light_shield_micron_x1.stl, [b]_light_shield_voron_x1.stl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]
2024-10-28 fixed missing chamfer on main body
    [ant_head_main_body_voron_x1.stl, ant_head_main_body_x1.stl]
2024-10-28 fixed ducts missing fillet
    [[a]_left_duct_HB92_x1.stl, [a]_left_duct_x1.stl, [a]_right_duct_HB92_x1.stl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]
2024-10-28 renamed files for proper prefix
    [[c]_diffuser_micron.stl, [c]_diffuser_voron.stl, [o]_light_shield_micron_x1.stl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]
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2024-10-29 fixed issue that was introduced with the LED insert change with how the grill fits
    [ant_head_main_body_voron_x1.stl, ant_head_main_body_x1.stl]
2024-10-29 Add CAD/Base_grill v4
    [Base_grill v4.step]
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2024-10-30 sherpa / orbiter changes , changelog in readme
    [Base_grill v4.step, Hotend_Base.step, [a]_left_duct_HB92_x1.stl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]
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2024-10-30 added salad fork logo cowling and LED , renamed led files to have correct prefix for filament type
    [[c]_diffuser_salad_fork_x1.stl, [o]_light_shield_salad_fork_x1.stl, ant_head_main_body_salad_fork_O2_x1.stl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]
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2024-10-30 updated right ducts
    [[a]_right_duct_HB92_x1.stl, [a]_right_duct_standard_x1.stl]
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2024-11-12 added HF and UHF ducts and main bodies updated cad with all the latest changes as well
    [[a]_dragon_x1.stl, [a]_hf_left_duct_hb92_x1.stl, [a]_hf_left_duct_x1.stl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]
2024-12-14 Fixed #6
    [[a]_left_duct_HB92_x1.stl]
2024-12-16 various fixes/changes
    Changed magnet holes size based on feedback from stealthchanger dev
    fixed the left HB92 duct geometry
    uploaded latest cad file V48
    [[a]_dragon_x1.stl, [a]_hf_left_duct_hb92_x1.stl, [a]_hf_left_duct_x1.stl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]
2025-01-05 pushed stls and cad for latest changes to 2020 anthead carriage, as well as uploaded stls and latest cad for leafcutter filament cutter mod
    [Left_Duct_SF_LeafCutter.stl, Main_Body_Micron_SF_LeafCutter.stl, [a]_G2_front_body_leafcutter_x1.stl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]
2025-01-05 various minor updates
    updated rapido mount to sit lower for HF and UHF ducts
    fixed hole size on right ducts
    added updated hotend mounts with HF and UHF nozzle location
    [Hotend_Base v16.step, [a]_hf_right_duct_x1.stl, [a]_rapido_x1.stl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]
2025-01-18 Added Screwless Fan Mount
    [Dragon.stl, Rapido.stl, Revo_Voron.stl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]
2025-02-06 various updates and fixed #11
    * updated all hotend mounts to fix the mounting screw length to m3x25
    * added support for Dragon Ace hotend
    * added support for ReVolcano (Revo voron heatsink with hemera heatbreak and volcano heater)
    * fixed rapido mount to use correct mounting m2.5 screws
    [[a]_dragon_ace_m2.5_x1.stl, [a]_dragon_ace_x1.stl, [a]_dragon_m2.5_x1.stl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]
2025-02-06 updated main assembly cad , hotend line up cad, and hotend base mount cad
    [Hotend_Base v16.step, Hotend_Base v22.step, Hotend_Base.step]
2025-02-11 carto cnc carriage adapters and voron logo hf leafcutter body have been added
    [Carto_CNC_Carriage_Anthead_Adapter.step, HF_CartoCNC_Anthead_Adapter.stl, SF_CartoCNC_Anthead_Adapter.stl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]
2025-02-14 Front Cowl and Insert
    [AntPap_Front_Cowl_Insert_x1.stl, AntPap_Front_Cowl_x1.stl]
2025-02-15 Uploaded STLs and CAD
    [AntPap-BaseCover_HGXv1_x1.stl, AntPap_Front_Cowl_Insert_x1.stl, AntPap_Front_Cowl_x1.stl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]
2025-02-16 Re-uploaded CAD with adjustments to built in supports and reorganized STLs
    All built in supports were adjusted for easier printing. Updated STLs and CAD. Reorganized STLs
    [AntHead-HexZero-ZeroClick-Left-Duct v1.stl, AntPap-BaseCover_HGXv1_x1.stl, AntPap_Front_Cowl_Insert_x1.stl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]
2025-02-16 STL corrections
    [AntPap-BaseCover_HGXv1_x1.stl, AntPap_Light_Shield_KevinAkaSam-Papilio-Logo-AntPap_x1.step, AntPap_Light_Shield_KevinAkaSam-Papilio-Logo-AntPap_x1.stl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]
2025-02-17 Added work in progress leafcutter and fix to fan duct mounting hole in mid piece
    [AntPap_Front_Cowl_Insert_x1.stl, AntPap_PapilioLite_BaseMid_HGXv1_x1.stl, RevoMount.stl]
2025-02-18 update to leaf cutter changes
    [Trident_Anthead_Umbilical v1.step, [a]_blade_holder_x1.stl, [a]_dragon_ace_m2.5_x1.stl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]
2025-02-18 Added missing tzv6 mounts and re uploaded latest hotend line up cad file
    [[a]_tzv6_v6nozzle_m2.5_x1.stl, [a]_tzv6_v6nozzle_x1.stl]
2025-02-19 Leafcutter parts added
    [AntPap_BaseCover_Leafcutter_HGXv1_x1.stl, AntPap_FrontCover_RunoutSensor-x1.stl, AntPap_Front_Cowl_Insert_x1.stl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]
2025-02-19 updated stls
    [AntPap-BaseCover_Leafcutter-HGXv1_x1.stl, AntPap_PapilioLite_Leafcutter-BaseMid-HGXv1_x1.stl, RevoMount_Leafcutter.stl]
2025-02-19 file update
    [AntPap-BaseCover_Leafcutter-HGXv1_x1.stl, AntPap_BaseCover_Leafcutter-HGXv1_x1.stl, AntPap_BaseCover_Leafcutter_HGXv1_x1.stl]
2025-02-19 Updated CAD
    [AntPap_FrontCover_RunoutSensor-x1.stl]
2025-02-20 Added LGX lowerbase
    [AntPap_PapilioLite-BaseLower_HGX_x1.stl, AntPap_PapilioLite-BaseLower_LGX_x1 (2).stl]
2025-02-20 Moved LGX stl
    [AntPap_PapilioLite-BaseLower_LGX_x1.stl]
2025-02-20 LGX files
    [AntPap_PapilioLite-BaseLower_LGX_x1.stl, AntPap_PapilioLite_BaseMid_LGX.stl, LGX-Bearing-Pad.f3d]
2025-02-20 Reorganized Files
    [2x_Idler_Pulley_F623_r3.1.stl, 2x_Idler_Pulley_r3.1.stl, AntHead-HexZero-ZeroClick-Left-Duct v1.stl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]
2025-02-20 Renamed file
    [AntPap_BaseCover_LEAFCUTTER-HGXv1_x1.stl]
2025-02-20 removed archive
    [AntPap-BaseCover_HGXv1_x1.stl, AntPap_BaseCover_Leafcutter-HGXv1_x1.stl, AntPap_FrontCover_RunoutSensor-x1.stl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]
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2025-02-24 User mod for LED Solder fixture.
    [AntHead LED Fixture Clamp.stl, AntHead LED Fixture v4.f3d, AntHead LED Fixture v4.step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]
2025-02-27 organized and fixed naming of the files to be more consistent across all variations of the files
    [[a] x1c x1test.stl, [a]_bambu_x1c_m2.5_x1.stl, [a]_bambu_x1c_x1.stl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]
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2025-03-16 Klicky Duct
    Anthead Klicky Duct
    [Anthead_Right_Duct_Klicky Mount.STEP, Anthead_Right_Duct_Klicky Mount.STL]
2025-04-04 Added WW-BMG to usermods
    [AntHead WW-BMG - Main Body.step, AntHead WW-BMG - Motor Plate.step, AntHead WW-BMG - Motor Plate.stl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]
2025-04-07 Standard flow nozzle LEDs
    [Print_LED v1.step, [a]_Nozzle_LED_Carrier.stl, [a]_Nozzle_LED_Restraint.stl]
2025-04-11 fixed #37 , fixed #35 , fixed #31
    added ziptie mounts and fixed issue with tensioner arms built in support as well as the countersunk hole for the tension spring
    [[a]_left_duct_hb92_lc_x1.stl, [a]_left_duct_hb92_x1.stl, [a]_left_duct_hf_hb92_lc_x1.stl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]
2025-04-15 fixed issue with revolcano mount
    [[a]_reVolcano_m2.5_x1.stl, [a]_reVolcano_x1.stl]
2025-04-30 Add bearing cutter usermod
    [FitTest_683.step, FitTest_683.stl, FitTest_MR63ZZ.step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]
2025-05-28 fixed #39 and fixed #42
    [MGN12_Carriage_Mount.stl, [a]_blade_holder_x1.stl, [a]_toolhead_board_mount_micron_v0.stl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]
2025-06-11 update to WWG2 to fix minor printability issues as well as the alignment on the filament sensors
    [Carto_CNC_Carriage_Anthead_Adapter.step, [a]_26mm_blade_holder_x1.stl, [a]_blade_holder_x1.stl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]
2025-07-28 anthead updates fixed #46 fixed minor offset between hot mounts and ducts , added m2 flanged heatsets for the ptfe path for the filament cutter
    [Hotend_Base v22.step, Hotend_Base v31.step, NH36_Board_Cover.step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]
2025-07-28 fixed hotend mount orientation
    [[a]_dragon_ace_m2.5_x1.stl, [a]_dragon_ace_x1.stl, [a]_dragon_m2.5_x1.stl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]
2025-07-28 added latest leaf cutter files to main cad and STLs
    [[a]_26mm_blade_holder_x1.stl, cutting_arm_x1.stl]
2025-08-02 fixed offset between ducts and probe mounts issue after last change
    [beacon_carto_hf_x1.stl, beacon_carto_sf_x1.stl, beacon_carto_uhf_x1.stl]
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2025-10-02 fixed orientation on g2 stls
    [[a]_front_body_x1.stl, pug_mount_a_x1.stl, pug_mount_b_x1.stl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]
2025-11-22 added anthead crossbow mod to usermods as well as bowden extruder top to anthead extruders
    [Anthead_Bowden.step, [a]_anthead_bowden_x1.stl, [a]_depressor_arm.stl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]
2025-11-27 main body access holes update
    [ant_head_main_body_micron_o2_hf_x1.stl, ant_head_main_body_micron_o2_sf_x1.stl, ant_head_main_body_micron_o2_uhf_x1.stl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]
2026-03-16 fixed files with duplicate parts in them , no need to reprint
    [[a]_chube_for_ants_M2.5_x1.stl, [a]_chube_for_ants_x1.stl, [a]_dragon_ace_m2.5_x1.stl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]
2026-03-18 fixed missng chube compact hotend cad , updated grills to fit m2.5 shcs for hotend fan
    [[a]_hex_grill_x1.stl, [a]_open_grill_x1.3mf, [a]_open_grill_x1.stl]
2026-05-15 extend usermod: crossbow wwg2 no sensors
    Adds a crossbow-compatible wwg2 body with the switch cavities filled in
    [WWG2_Anthead_Crossbow_NoSensors.step, wwg2_front_body_no_sensors_x1.stl]
2026-06-24 fixed revolcano mounting holes
    [[a]_reVolcano_m2.5_x1.stl, [a]_reVolcano_x1.stl]
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

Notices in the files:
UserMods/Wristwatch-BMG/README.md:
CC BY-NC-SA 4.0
